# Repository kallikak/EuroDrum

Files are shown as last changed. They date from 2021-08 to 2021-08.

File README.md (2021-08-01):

# EuroDrum
Firmware source and schematics for the "Hit It!" Eurorack module.

<table>
  <tr>
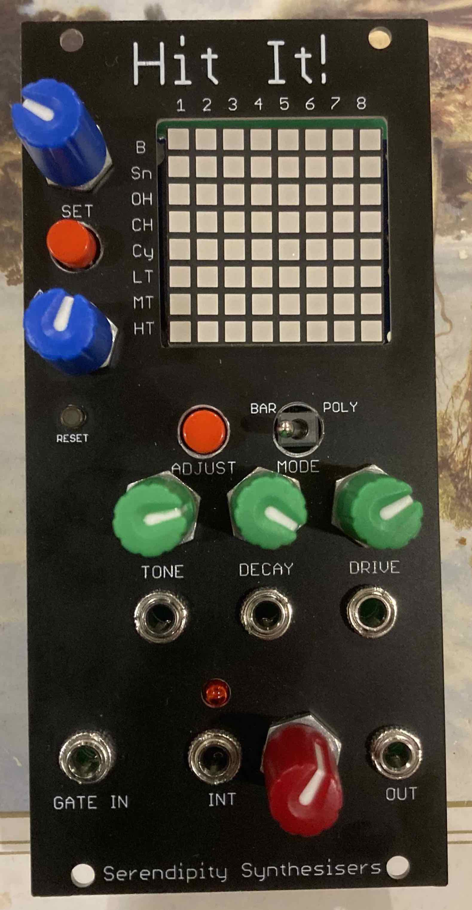
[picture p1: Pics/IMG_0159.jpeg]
    <td></td>
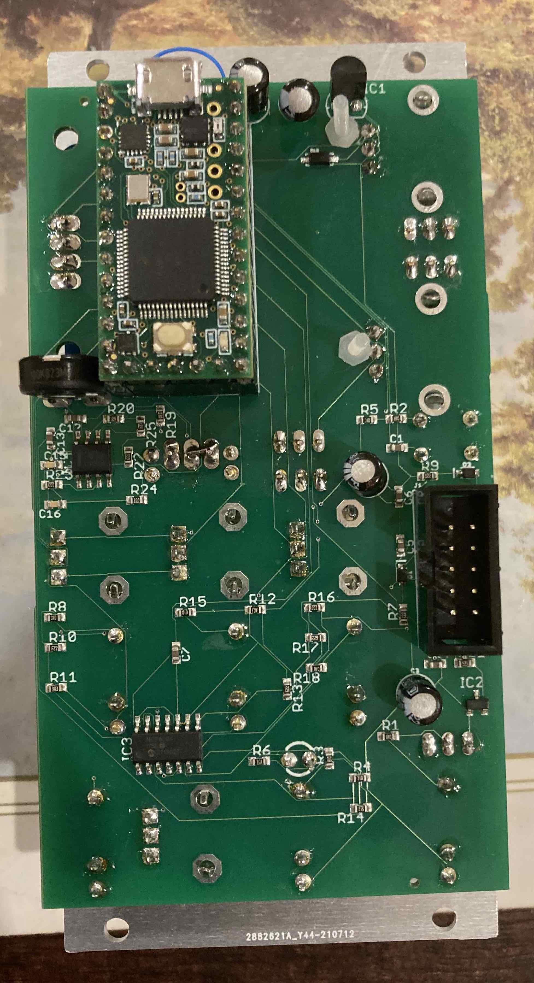
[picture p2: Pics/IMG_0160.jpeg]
    <td></td>
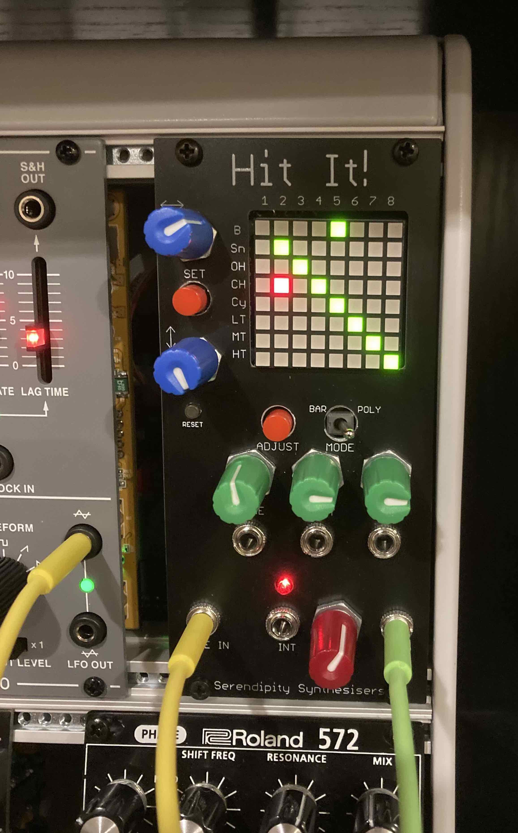
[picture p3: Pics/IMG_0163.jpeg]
    <td></td>
  </tr>  
</table>

This YouTube video gives a [brief overview](https://youtu.be/IKqNawbhtcc), and this one shows the [pitch CV mode](https://youtu.be/h47teE46W28).

The two encoders on the left let you move a cursor around the LED matrix, and the SET button toggles a connection between a beat (along the top) and a drum sample (down the side).

In "Bar" mode, the bar length is up to 8 beats, and the lit LEDs connect a beat to the instruments to be played on that beat.
In "Poly" mode, the lit LEDs mean play the corresponding instrument once every *n* beats.

Tone controls a LP filter, increasing cutoff until 12 o'clock, then decreasing while adding resonance. Decay is a simple decay envelope, and drive adds waveshaper distortion. Each control has an associated CV input below.

For timing, there is external gate in, as well as an internally generated clock (that is normalled to the gate in), and of course the audio out.

Hitting adjust switches between control modes:

- Normal mode as shown in the images where the encoders and SET button make and break connections.
  - A long press of SET toggles between active and inactive states.
  - A very long press of SET enters barlength mode, where continuing to hold SET while turning the left-right encoder will adjust the bar length for BAR mode.
  - A long press of ADJUST will clear all connections.
  - Continuing to hold ADJUST will restore a default set of connections.
- Levels mode for setting the level of each instrument. A long press of ADJUST will restore the default levels.
- Kit mode for selecting between 7 kits.
  - Each instrument has an alternate sample
  - The pairs are Bass/Clap, Snare/Rimshot, Open-hat/Maracas, Closed-hat/Claves, Crash cymbal/Ride cymbal, Toms/Congas.
  - Access is by selecting one of 7 pre-defined combinations. This way the front markings keep a reasonable meaning when changing the allocation.
  - Cycle kits with the SET button when in this mode (the display will show a letter from A to G).
- Sequencer mode where the outputs are pitch CVs.
  - The CV offset range from -0.41V to +1V corresponding to 8 offsets from down a 4th to up an octave, following a pentatonic major or minor scale. 
  - The SET button switches between scales (a + on the display indicates major and - indicates minor).
  - A long press of adjust will enable and disable the sequencer mode.

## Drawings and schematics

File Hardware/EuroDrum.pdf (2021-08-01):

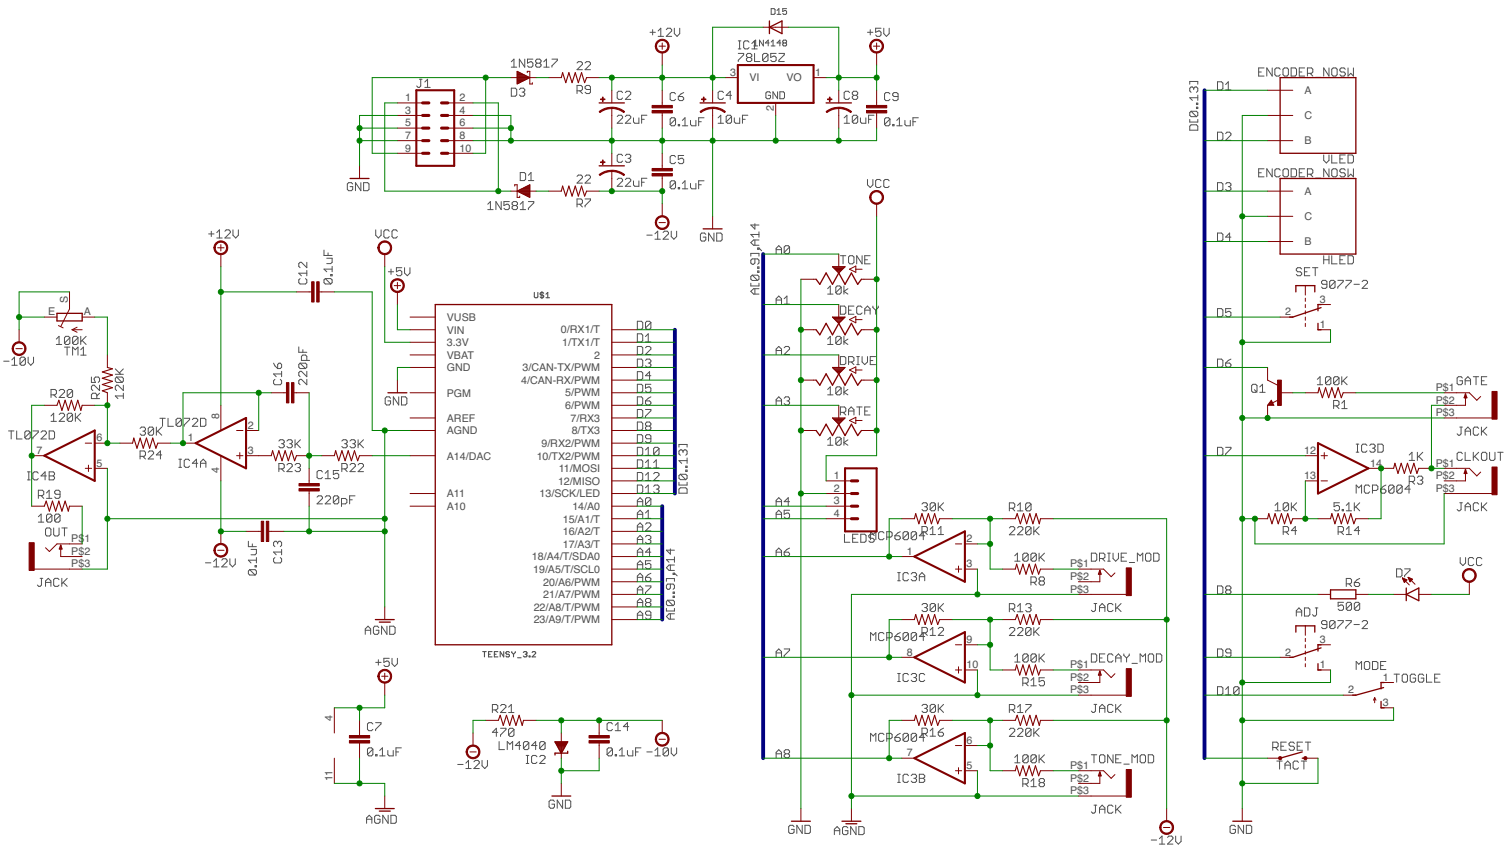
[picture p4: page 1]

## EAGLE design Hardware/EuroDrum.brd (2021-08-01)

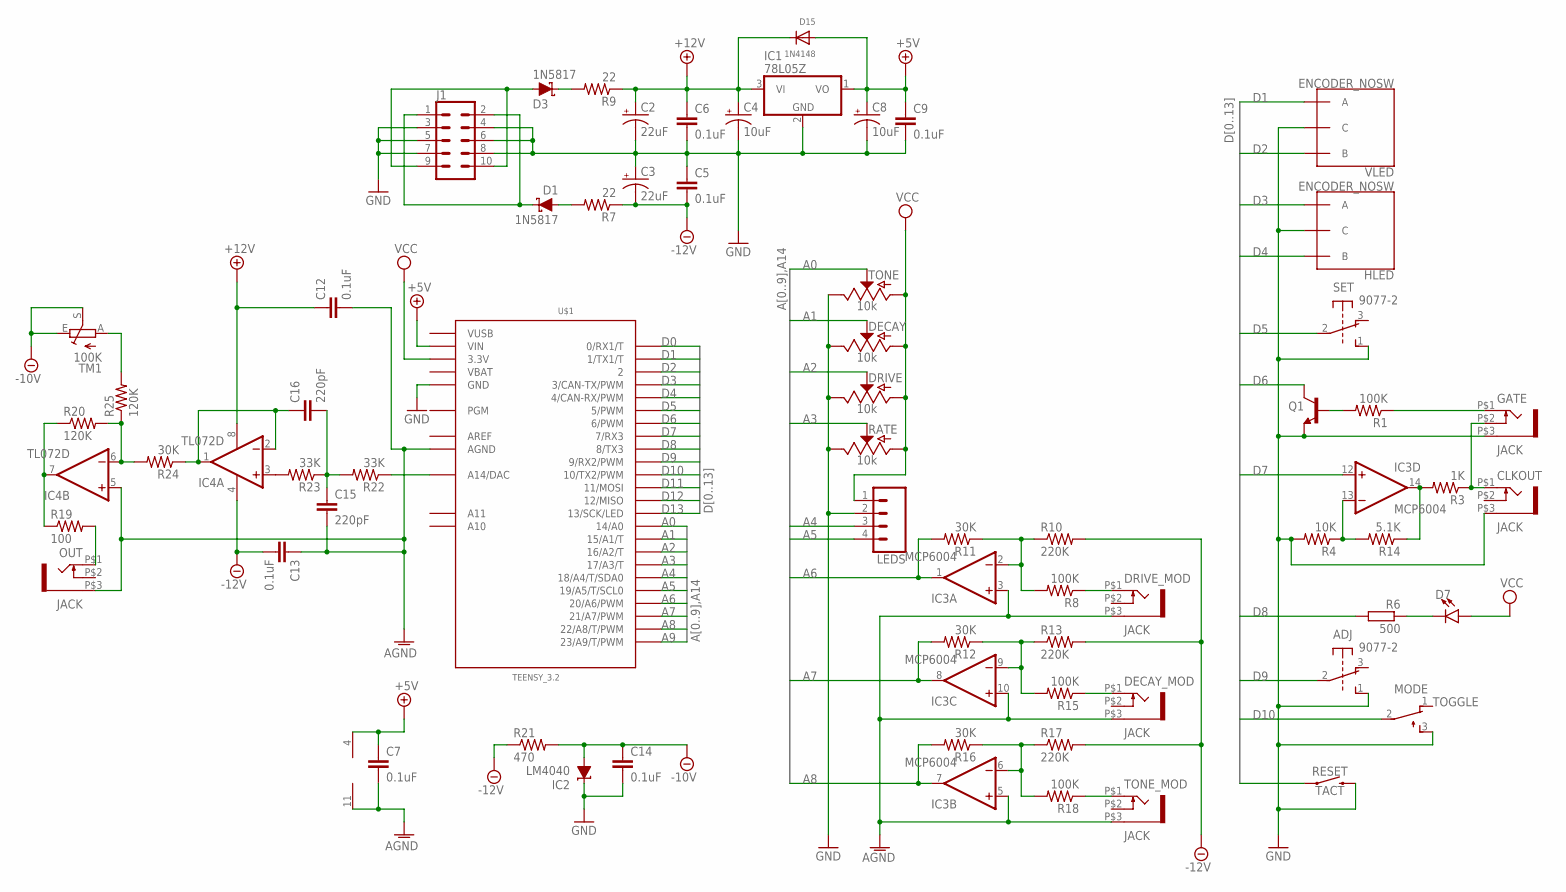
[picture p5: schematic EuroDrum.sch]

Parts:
ADJ: 9077-2
C2, C3: 22uF; CPOL-RADIAL-2.5MM-5MM
C4, C8: 10uF; CPOL-RADIAL-2.5MM-5MM
C5, C6, C7, C9, C12, C13, C14: 0.1uF; C0603K
C15, C16: 220pF; C0603K
CLKOUT: JACK; WQP-PJ301M-12_JACK
D1, D3: 1N5817; SOD-323
D7: LED3MM; LED_3MM
D15: 1N4148; SOD-123
DECAY: 10k; POT-PTH-ALPS
DECAY_MOD: JACK; WQP-PJ301M-12_JACK
DRIVE: 10k; POT-PTH-ALPS
DRIVE_MOD: JACK; WQP-PJ301M-12_JACK
GATE: JACK; WQP-PJ301M-12_JACK
HLED: ENCODER_NOSW
IC1: 78L05Z; TO92
IC2: LM4040; DBZ_R-PDSO-G3
IC3: MCP6004; SO14
IC4: TL072D; SO08
J1: CONN_05X2SHD; 2X5-SHROUDED
LEDS: CONN_04LONGPADS; 1X04_LONGPADS
MODE: TOGGLE; TL3XYO
OUT: JACK; WQP-PJ301M-12_JACK
Q1: BC549C; TO92-EBC
R1, R8, R15, R18: 100K; R0603
R3: 1K; R0603
R4: 10K; R0603
R6: 500; R0603
R7, R9: 22; R0603
R10, R13, R17: 220K; R0603
R11, R12, R16, R24: 30K; R0603
R14: 5.1K; R0603
R19: 100; R0603
R20, R25: 120K; R0603
R21: 470; R0603
R22, R23: 33K; R0603
RATE: 10k; POT-PTH-ALPS
RESET: TACT; TACTILE_SWITCH_PTH_6.0MM
SET: 9077-2
TM1: 100K; CA6H
TONE: 10k; POT-PTH-ALPS
TONE_MOD: JACK; WQP-PJ301M-12_JACK
U$1: TEENSY_3.2; TEENSY_3.0-3.2&LC_ALL_PINS
VLED: ENCODER_NOSW

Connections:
+5V: C7.1, C8.1 (+), C9.1, D15.A, IC1.1 (VO), IC3.4 (V+), U$1.VIN
+12V: C2.1 (+), C4.1 (+), C6.1, C12.1, D15.C, IC1.3 (VI), IC4.8 (V+), R9.1
-10V: C14.1, IC2.2 (A), R21.2, TM1.E, TM1.S
-12V: C3.2 (-), C5.2, C13.2, IC4.4 (V-), R7.1, R10.2, R13.2, R17.2, R21.1
A0: TONE.P$2 (S), U$1.14/A0
A1: DECAY.P$2 (S), U$1.15/A1 (15/A1/T)
A2: DRIVE.P$2 (S), U$1.16/A2 (16/A2/T)
A3: RATE.P$2 (S), U$1.17/A3 (17/A3/T)
A4: LEDS.3, U$1.18/A4 (18/A4/T/SDA0)
A5: LEDS.4, U$1.19/A5 (19/A5/T/SCL0)
A6: IC3.1 (OUT), R11.2, U$1.20/A6 (20/A6/PWM)
A7: IC3.8 (OUT), R12.2, U$1.21/A7 (21/A7/PWM)
A8: IC3.7 (OUT), R16.2, U$1.22/A8 (22/A8/T/PWM)
A9: U$1.23/A9 (23/A9/T/PWM)
AGND: C7.2, C12.2, C13.1, C15.2, DECAY_MOD.P$3 (1), DRIVE_MOD.P$3 (1), IC3.3 (+IN), IC3.5 (+IN), IC3.10 (+IN), IC3.11 (V-), IC4.5 (+IN), OUT.P$3 (1), TONE_MOD.P$3 (1), U$1.AGND
AREF: U$1.AREF
D0: U$1.0 (0/RX1/T)
D1: U$1.1 (1/TX1/T), VLED.A
D2: U$1.2, VLED.B
D3: HLED.A, U$1.3 (3/CAN-TX/PWM)
D4: HLED.B, U$1.4 (4/CAN-RX/PWM)
D5: SET.2, U$1.5 (5/PWM)
D6: Q1.C, U$1.6 (6/PWM)
D7: IC3.12 (+IN), U$1.7 (7/RX3)
D8: R6.2, U$1.8 (8/TX3)
D9: ADJ.2, U$1.9 (9/RX2/PWM)
D10: MODE.2, U$1.10 (10/TX2/PWM)
D11: RESET.1, U$1.11 (11/MOSI)
D12: U$1.12 (12/MISO)
D13: U$1.13 (13/SCK/LED)
GND: ADJ.1 (S), C2.2 (-), C3.1 (+), C4.2 (-), C5.1, C6.2, C8.2 (-), C9.2, C14.2, CLKOUT.P$3 (1), DECAY.P$1 (E), DRIVE.P$1 (E), GATE.P$3 (1), HLED.C, IC1.2 (GND), IC2.1 (C), J1.3, J1.4, J1.5, J1.6, J1.7, J1.8, LEDS.2, MODE.3 (S), Q1.E, R4.2, RATE.P$1 (E), RESET.3 (2), SET.1 (S), TONE.P$1 (E), U$1.GND, U$1.GND1 (GND), VLED.C
unnamed: D1.C, J1.1, J1.2
unnamed: IC3.9 (-IN), R12.1, R13.1, R15.2
unnamed: D3.A, J1.9, J1.10
unnamed: D3.C, R9.2
unnamed: DRIVE_MOD.P$1 (2), R8.1
unnamed: D1.A, R7.2
unnamed: IC3.2 (-IN), R8.2, R10.1, R11.1
unnamed: CLKOUT.P$1 (2), GATE.P$2 (3), R3.1
unnamed: DECAY_MOD.P$1 (2), R15.1
unnamed: IC3.6 (-IN), R16.1, R17.1, R18.2
unnamed: R18.1, TONE_MOD.P$1 (2)
unnamed: IC4.3 (+IN), R23.2
unnamed: Q1.B, R1.2
unnamed: C15.1, C16.2, R22.2, R23.1
unnamed: R22.1, U$1.RESET/DAC (A14/DAC)
unnamed: C16.1, IC4.1 (OUT), IC4.2 (-IN), R24.1
unnamed: GATE.P$1 (2), R1.1
unnamed: IC3.13 (-IN), R4.1, R14.2
unnamed: D7.K (C), R6.1
unnamed: IC4.6 (-IN), R20.2, R24.2, R25.1
unnamed: OUT.P$1 (2), R19.2
unnamed: IC4.7 (OUT), R19.1, R20.1
unnamed: R25.2, TM1.A
NOTE1: IC3.14 (OUT), R3.2, R14.1
VBAT: U$1.VBAT
VCC: D7.A, DECAY.P$3 (A), DRIVE.P$3 (A), LEDS.1, RATE.P$3 (A), TONE.P$3 (A), U$1.3.3V, U$1.3.3V1 (3.3V)
VUSB: U$1.VUSB

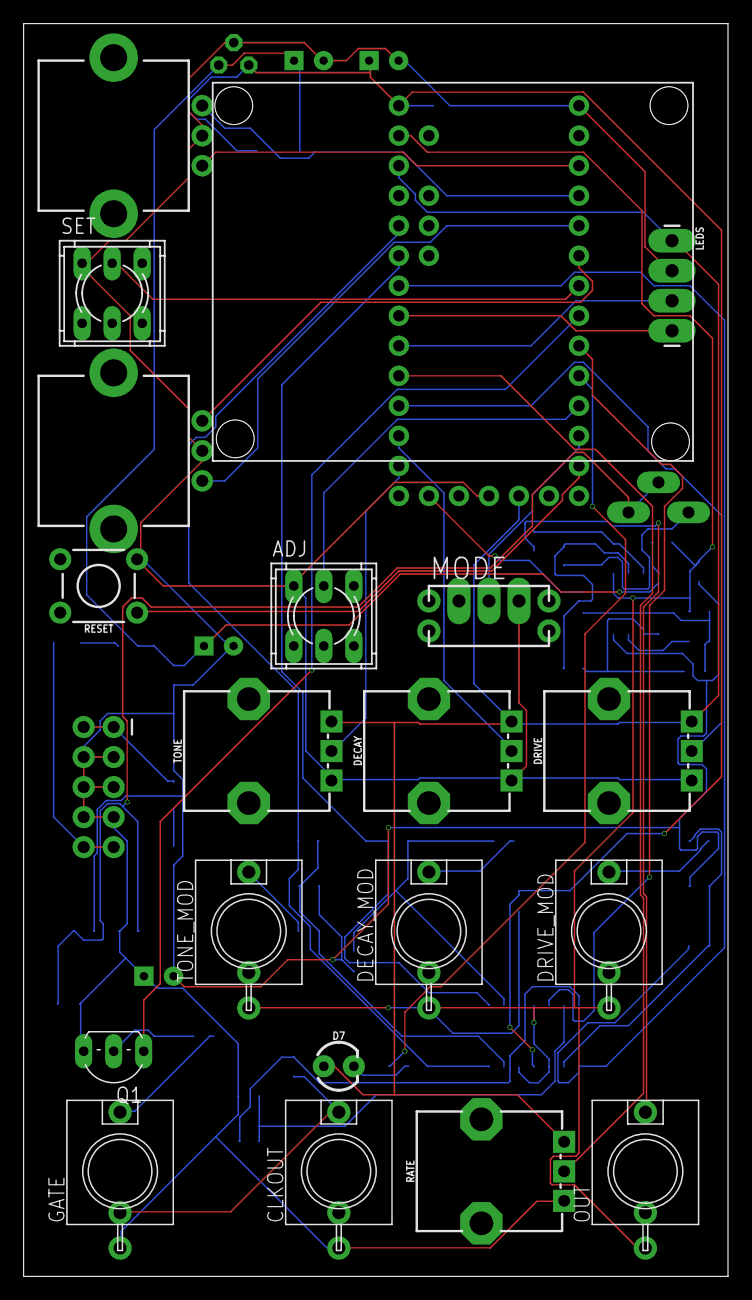
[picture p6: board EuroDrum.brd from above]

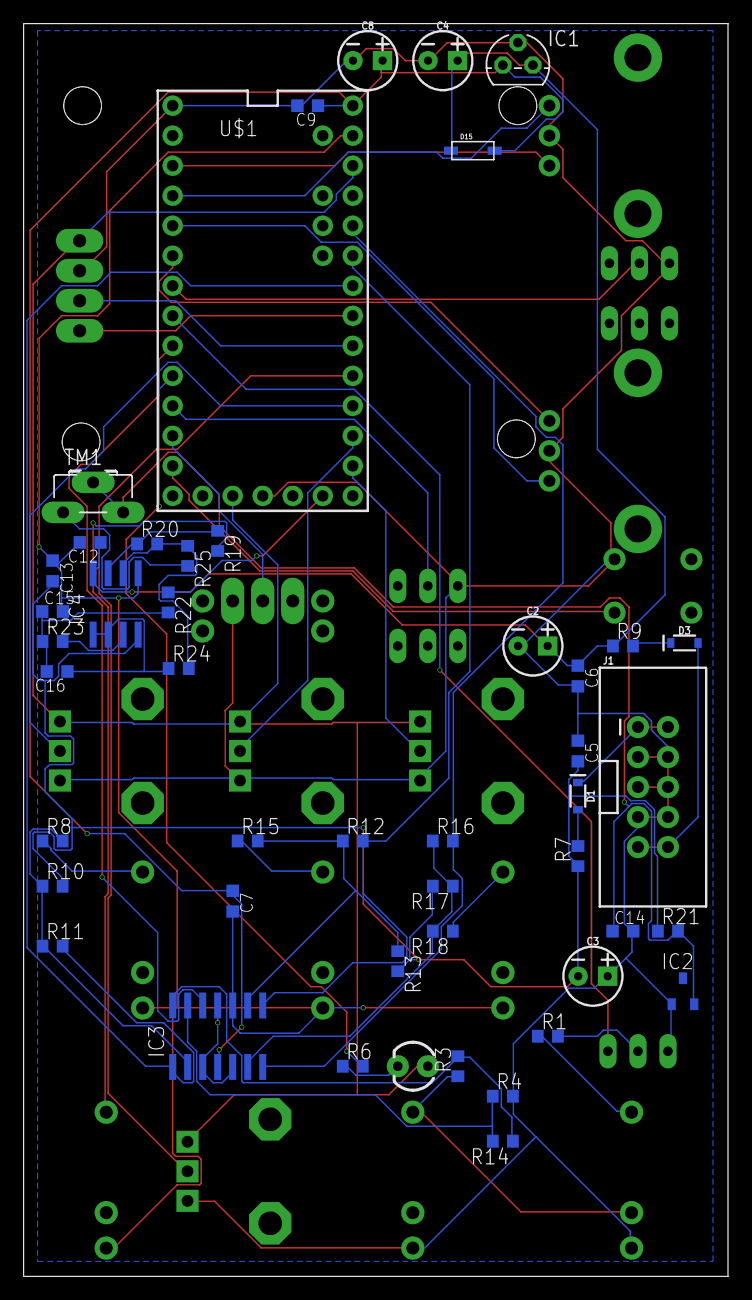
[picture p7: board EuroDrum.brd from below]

Board: 2 copper layers, 59.6 x 106.0 mm, 65 parts (46 on the bottom side), 51 nets.

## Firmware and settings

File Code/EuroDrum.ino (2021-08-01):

#include "Bounce2.h"
#include <IntervalTimer.h>
#include <Encoder.h>

#include "Synth.h"

#include "EuroDrum.h"
#include "LEDMatrix.h"
#include "drum_defs.h"
#include "drum_samples.h"

typedef enum { NONE, SHORT, PENDINGLONG, LONG, VERYLONG, ROSE } buttonpress;

int curMode = BARMODE;

// CVs
#define GATECV 6
#define CLOCKCV 7
#define DRIVECV A6
#define DECAYCV A7
#define TONECV A8
#define DAC A14

// pots
#define TONE A0
#define DECAY A1
#define DRIVE A2
#define RATE A3

typedef struct 
{
  int pin;
  int value;
} pot;

pot drivePot = {DRIVE, 0};
pot decayPot = {DECAY, 0};
pot tonePot = {TONE, 0};
pot ratePot = {RATE, 0};

// buttons
#define SET 5
#define ADJUST 9
#define RESET 12

#define LONG_PRESS_MILLIS 300

typedef struct
{
  int pin;
  bool longpress;
  bool handled;
  Bounce *debouncer;
} button;

button setBtn = {SET, false, false, NULL};
button adjBtn = {ADJUST, false, false, NULL};

#define RATELED 8
#define MODE 10

// encoders
typedef struct
{
  int pinA;
  int pinB;
  Encoder *enc;
  int pos;
} encoder;

encoder lr = {1, 2, NULL, 0};
encoder ud = {3, 4, NULL, 0};

IntervalTimer timer;

volatile bool active = false;

volatile bool rateLEDstate = false;
volatile bool trigger = false;
volatile int beat = 0;
volatile int barlength = 8;
volatile unsigned long totalbeat = 0;

bool major = true;
bool playsequencer = false;

controlmode curcontrol = NORMAL;
int curkit = 0;

void setupButtons()
{
  pinMode(setBtn.pin, INPUT_PULLUP);
  setBtn.debouncer = new Bounce();
  setBtn.debouncer->attach(setBtn.pin);
  setBtn.debouncer->interval(50);
  pinMode(adjBtn.pin, INPUT_PULLUP);
  adjBtn.debouncer = new Bounce();
  adjBtn.debouncer->attach(adjBtn.pin);
  adjBtn.debouncer->interval(50);
}

void setupEncoders()
{
  pinMode(lr.pinA, INPUT_PULLUP);
  pinMode(lr.pinB, INPUT_PULLUP);
  lr.enc = new Encoder(lr.pinA, lr.pinB);
  
  pinMode(ud.pinA, INPUT_PULLUP);
  pinMode(ud.pinB, INPUT_PULLUP);
  ud.enc = new Encoder(ud.pinA, ud.pinB);
}

int16_t movingaverage(int16_t newvalue, int16_t avg, int n)
{
  if (newvalue < 3)
    return 0;
  if (newvalue > MAXPOT - 3)
    return MAXPOT;
  else
    return (n * avg + newvalue) / (n + 1);
}

void handleRatePot()
{
  // linear tempo from 30 to 900 bpm  - pad a bit so extremes don't drop out
  int d = max(30, min(900, map(ratePot.value, 0, MAXPOT, 28, 902)));
  timer.update((int)(60000.0 / d * 1000 / 2));  // two updates each interval for off and on
}

void checkTempo()
{
  int newv = movingaverage(analogRead(ratePot.pin), ratePot.value, 5);
//  int newv = analogRead(ratePot.pin);
  if (abs(newv - ratePot.value) > 10)
  {
    ratePot.value = newv;
    handleRatePot();
  }
}

void timerFired()
{
  rateLEDstate = !rateLEDstate;

// with normalled circuit this is no longer necessary
//#if !EURORACK
//  // only flash the LED if internal
//  digitalWrite(RATELED, rateLEDstate);
//  if (rateLEDstate) // on trigger
//  {
//    updateBeats();
//  }
//#endif

  // gate the output anyway
  digitalWrite(CLOCKCV, active && rateLEDstate ? HIGH : LOW);
}

void updateBeats()
{
  trigger = active;
  ++beat;
  beat %= barlength;
  totalbeat++; 
}

buttonpress getPress(button *btn)
{
  btn->debouncer->update();
  int d = btn->debouncer->duration();
  int pd = btn->debouncer->previousDuration();
  if (!btn->handled && !btn->longpress && !btn->debouncer->read())
  {
    if (d >= 3 * LONG_PRESS_MILLIS)
    {
      btn->longpress = true;
      return VERYLONG;
    }
    else if (d >= LONG_PRESS_MILLIS)
    {
      return PENDINGLONG;
    }
  }
  else if (btn->debouncer->rose())
  {
    if (!btn->handled)
    {
      if (!btn->longpress)
      {
        if (pd > LONG_PRESS_MILLIS && pd < 3 * LONG_PRESS_MILLIS)
        {
          return LONG;
        }
        else
        {
          return SHORT;
        }
      }
    }
    btn->longpress = false;
    btn->handled = false;
    return ROSE;
  }
  return NONE;
}

void checkButtons()
{
  buttonpress setpress = getPress(&setBtn);
  switch (setpress)
  {
    case SHORT:
      if (setBtn.longpress)
        setBtn.longpress = false;
      else if (curcontrol == NORMAL)
        toggleCurPixel();
//      else if (curcontrol == LEVELS && cursamplemode == MIXED)
//        showLevels();
      else if (curcontrol == SAMPLESEL)
      {
        curkit = (curkit + 1) % numKits();
        setKit(curkit);
        showSampleSet();
      }
      else if (curcontrol == SEQUENCER)
      {
        major = !major;
        showSequencer();
      }
      break;
    case LONG:
      active = !active;
      updateForActivation();
      break;
    case VERYLONG:
      if (curcontrol == NORMAL)
        curcontrol = BARLENGTH;
      break;
    case ROSE:
      if (curcontrol == BARLENGTH)
        curcontrol = NORMAL;
      break;
    case PENDINGLONG:
    case NONE:
      break;
  }
  
  buttonpress adjpress = getPress(&adjBtn);
  switch (adjpress)
  {
    case SHORT:
      curcontrol = (controlmode)((curcontrol + 1) % 4);
      if (curcontrol == LEVELS)
        showLevels();
      else if (curcontrol == SAMPLESEL)
        showSampleSet();
      else if (curcontrol == SEQUENCER)
        showSequencer();
      else
        redraw();
      break;
    case VERYLONG:
      if (curcontrol == NORMAL)
      {
        setdefault();
        adjBtn.handled = true;
      }
      break;
    case PENDINGLONG:
      if (curcontrol == LEVELS)
      {
        setDefaultLevels();
        setLevels();
        showLevels();
        adjBtn.handled = true;
      }
      else if (curcontrol == SEQUENCER)
      {
        playsequencer = !playsequencer;
        setDAC(!playsequencer);
        adjBtn.handled = true;
        showSequencer();
      }
      else if (curcontrol == NORMAL)
      {
        clear();
      }
      break;
    case LONG:
    case ROSE:
    case NONE:
      break;
  }
}

void checkMode()
{
  int newMode = digitalRead(MODE);
  if (newMode != curMode)
  {
    int prevMode = curMode;
    curMode = newMode;
    curcontrol = NORMAL;
    switchMode(prevMode, newMode);
  }
}

void checkEncoders()
{
  if (curcontrol == SAMPLESEL || curcontrol == SEQUENCER)
    return;
  int pos, dx = 0, dy = 0;
  
  pos = lr.enc->read();
  if (pos != lr.pos && pos % 8 == 0) 
  {  
    dx = pos > lr.pos ? -1 : 1;
    lr.pos = pos;
  }
  
  pos = ud.enc->read();
  if (pos != ud.pos && pos % 8 == 0) 
  {  
    dy = pos > ud.pos ? -1 : 1;
    ud.pos = pos;
  }

  if (dx || dy)
  {
    updateCursor(dx, dy);
    if (curcontrol == LEVELS)
      setLevels();
  }
}

static bool laststate = false;
void gateCVint()
{
  bool state = digitalReadFast(GATECV);
  if (state != laststate)
  {
    laststate = state;
    digitalWrite(RATELED, state);
    if (state)
    {
      updateBeats();
    }
  }
}

void handleDecay()
{
  handleSynthDecay(analogRead(DECAY), analogRead(DECAYCV));
}

void handleTone()
{
  handleSynthTone(analogRead(TONE), analogRead(TONECV));
}

void handleDrive()
{ 
  handleSynthDrive(analogRead(DRIVE), analogRead(DRIVECV));
}

void pin_reset() 
{
  SCB_AIRCR = 0x05FA0004;
}

// pentatonic:   0 2 5 7 9
// pentatonic_m: 0 3 5 7 10
int notesmajor[] = {12, 9, 7, 5, 2, 0, -3, -5};
int notesminor[] = {12, 10, 7, 5, 3, 0, -2, -5};

void sendNote_direct(int n)
{
  static float semitone = 4096 / 3.3 / 4 / 12; // 4096 DAC resolution, 3.3V, amp gain of 4, 12 steps in 1V octave
  // convert to CV and write to pin 14
  // adjust the trimmer pot so 1.65V goes to 0V out
  // 1.65V is 2048
  // 1 octave up is then 1V out
  // since gain is 4, that means an output of 0.25V
  // full range is 4096 => 3.3V, so 0.25V is 4096 / 3.3 / 4
  int v = round(2048 - n * semitone);
//  Serial.print(beat);
//  Serial.print(": ");
//  Serial.print(v);
//  Serial.print("V for note ");
//  Serial.println(n);
  analogWrite(DAC, v);
}

void sendNote(int n)
{
  /* 
   * 0 to 1 into AudioOutputAnalog maps from 0 to 3.3V (analog ref voltage) 
   * the following amp has gain of 4 (and offset to make it AC)
   * so 0.5 to dac is 0V output from the amp
   * 0.65152 to dac will be 1.65 + 0.25 = 1.9V from the DAC, 1.0V from the amp
   * so a semitone step is 0.25 / 1.65 / 12 = 0.1263
   */
  static float semitone = 0.25 / 1.65 / 12;
  float v = 0.5 + n * semitone;
//  Serial.print(beat);
//  Serial.print(": ");
//  Serial.print(v);
//  Serial.print("V for note ");
//  Serial.println(n);
  setDACLevel(v);
}

#define NO_NOTE -1000

int playDACIfSet(int i)
{
  int note = 0;
  bool update = false;
  
  for (int j = 0; j < 8; ++j)
  {
    if (isSet(i, j))
    {
      update = true;
      note += (major ? notesmajor : notesminor)[7 - j];
    }
  }

  return update ? note : NO_NOTE;
}

void playDAC()
{
  int note = 0;
  if (curMode == BARMODE)
  {
    note = playDACIfSet(beat);
  }
  else
  {
    for (int j = 1; j <= 8; ++j)
    {
      if (totalbeat % j == 0)
      {
        int note2 = playDACIfSet(j - 1);
        if (note2 != NO_NOTE)
          note += note2;
      }
    }
  }
  if (note != NO_NOTE)
    sendNote(note);
}

void play()
{
  if (playsequencer)
  {
    playDAC();
  }
  else
  {
    if (curMode == BARMODE)
    {
      playIfSet(beat, beat == 0);
    }
    else
    {
      for (int j = 1; j <= 8; ++j)
      {
        if (totalbeat % j == 0)
        {
          playIfSet(j - 1, false);
        }
      }
    }
  }
}

void setup() 
{
//  analogReadResolution(12);
  analogWriteResolution(12);

  pinMode(DRIVE, INPUT);
  pinMode(DECAY, INPUT);
  pinMode(TONE, INPUT);
  pinMode(RATE, INPUT);
  
  pinMode(DRIVECV, INPUT);
  pinMode(DECAYCV, INPUT);
  pinMode(TONECV, INPUT);
  pinMode(GATECV, INPUT_PULLUP);
  pinMode(CLOCKCV, OUTPUT);
  
  pinMode(RESET, INPUT_PULLUP);
  
  pinMode(RATELED, OUTPUT);
  pinMode(MODE, INPUT_PULLUP);
  
  setupEncoders();
  setupButtons();

  setupMatrix();

  setupSynth();
  
  attachInterrupt(GATECV, gateCVint, CHANGE);
  attachInterrupt(RESET, pin_reset, FALLING);
  
  timer.begin(timerFired, 1000);
  checkTempo();
}

int loopcount = 0;

void loop() 
{
  loopcount++;

  if (trigger)
  {
    trigger = false;
    play();
    return;
  }
  
  if (loopcount % 10 == 0)
  {
    checkTempo();
//    gateCVint();
    checkButtons();
  }
  
  handleDecay();
  handleTone();
  handleDrive();

  checkEncoders();
  
  if (loopcount % 100 == 0)
  {
    checkMode();
  }
  
  if (loopcount % 100000 == 0)
  {
    DBGn(loopcount)Serial.println(AudioMemoryUsageMax());    
  }
}

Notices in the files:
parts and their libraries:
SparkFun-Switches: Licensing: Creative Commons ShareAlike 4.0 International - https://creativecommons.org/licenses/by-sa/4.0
